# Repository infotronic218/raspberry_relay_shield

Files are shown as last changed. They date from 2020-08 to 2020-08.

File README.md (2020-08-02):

# Raspberry Pi 3 4 relays channels shield designed with Kicad

## The project is design using Kicad 5.1.5 

## The relay is drived by transistors

## Schematic

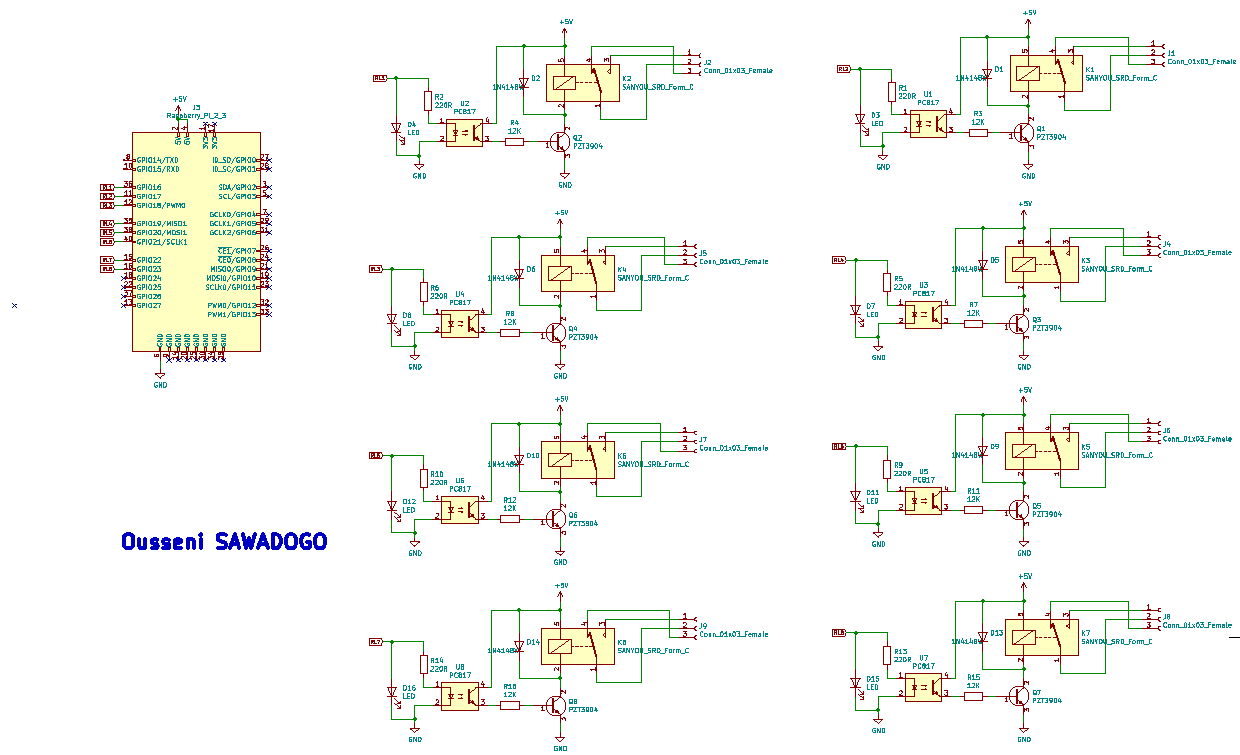
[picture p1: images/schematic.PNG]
Schematic


## Components side 
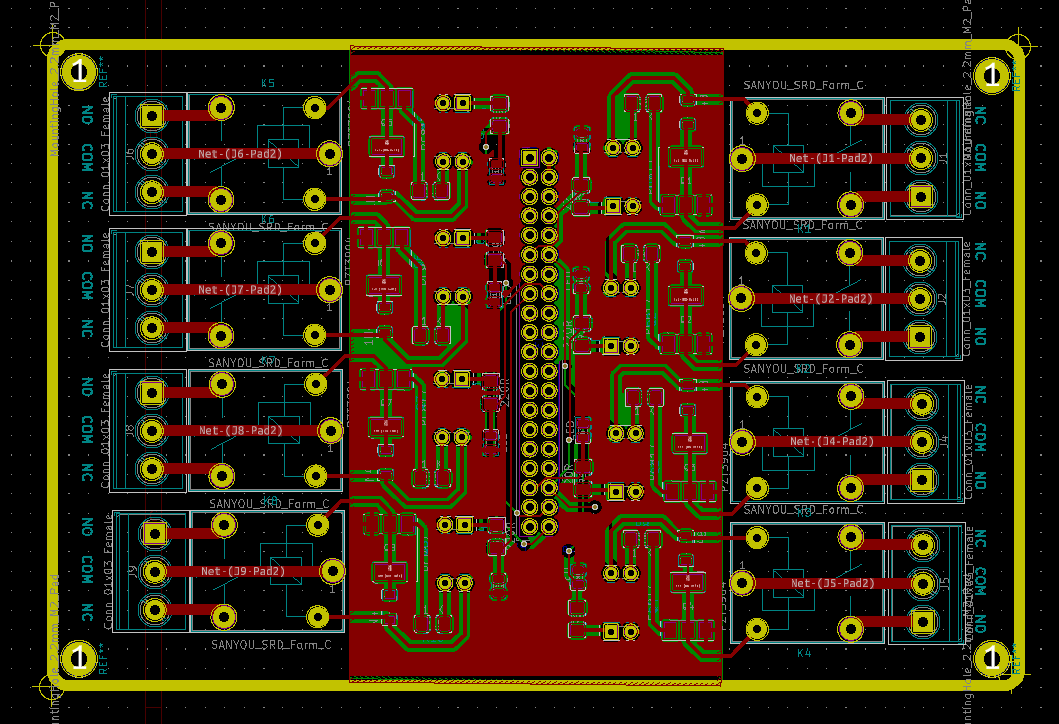
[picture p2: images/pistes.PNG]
Components side


## 3D View of the circuit
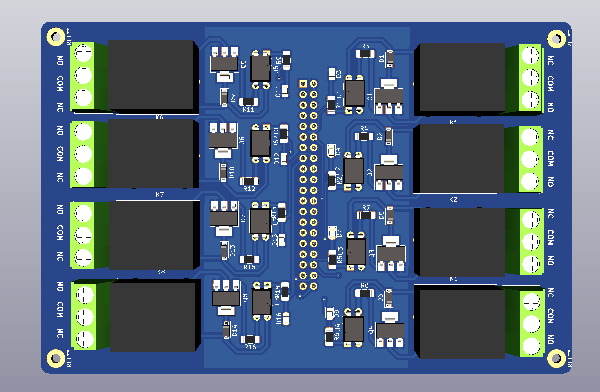
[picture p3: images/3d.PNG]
3D View


## To contact me 
[My portfolio at this url ](https://www.oussenisawadogo.me)

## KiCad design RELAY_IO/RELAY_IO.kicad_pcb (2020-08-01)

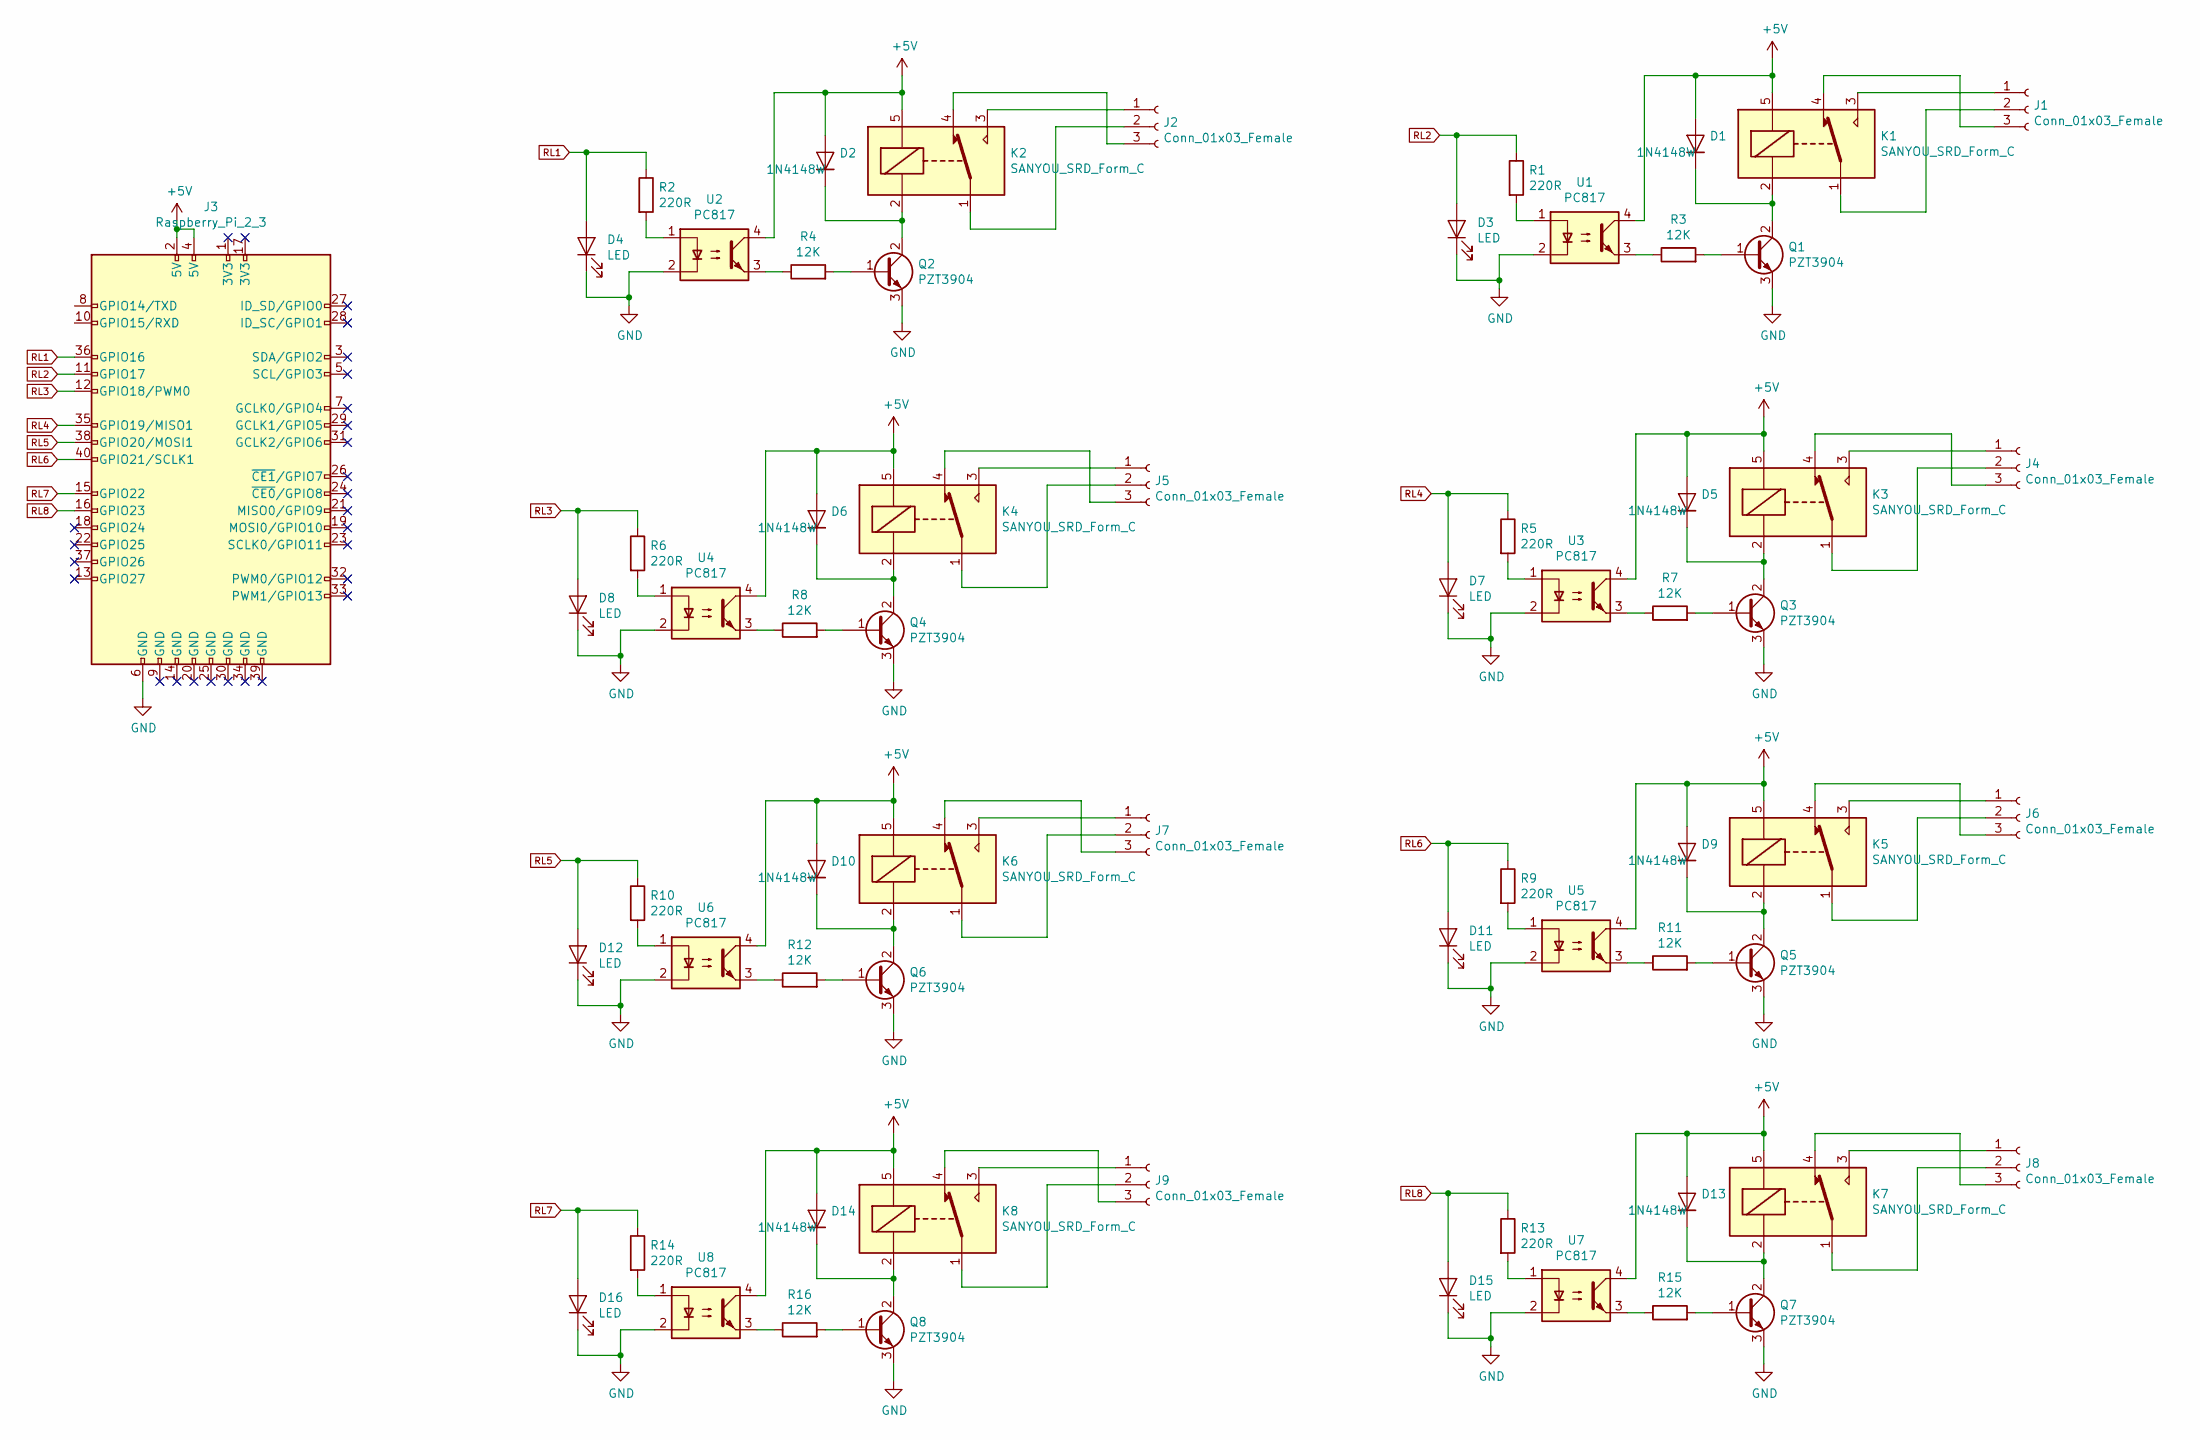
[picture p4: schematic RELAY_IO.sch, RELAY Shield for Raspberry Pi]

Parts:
D1, D2, D5, D6, D9, D10, D13, D14: 1N4148W; D_SOD-123
D3, D4, D7, D8, D11, D12, D15, D16: LED; LED_0805_2012Metric
J1, J2, J4, J5, J6, J7, J8, J9: Conn_01x03_Female; TerminalBlock_Phoenix_PT-1,5-3-5.0-H_1x03_P5.00mm_Horizontal
J3: Raspberry_Pi_2_3; PinSocket_2x20_P2.54mm_Vertical
K1, K2, K3, K4, K5, K6, K7, K8: SANYOU_SRD_Form_C; Relay_SPDT_SANYOU_SRD_Series_Form_C
Q1, Q2, Q3, Q4, Q5, Q6, Q7, Q8: PZT3904; SOT-223
R1, R2, R5, R6, R9, R10, R13, R14: 220R; R_1206_3216Metric_Pad1.42x1.75mm_HandSolder
R3, R4, R7, R8, R11, R12, R15, R16: 12K; R_1206_3216Metric_Pad1.42x1.75mm_HandSolder
U1, U2, U3, U4, U5, U6, U7, U8: PC817; DIP-4_W7.62mm

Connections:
+5V: D1.2 (A), D2.2 (A), D5.2 (A), D6.2 (A), D9.2 (A), D10.2 (A), D13.2 (A), D14.2 (A), J3.2 (5V), J3.4 (5V), K1.5, K2.5, K3.5, K4.5, K5.5, K6.5, K7.5, K8.5, U1.4, U2.4, U3.4, U4.4, U5.4, U6.4, U7.4, U8.4
GND: D3.1 (K), D4.1 (K), D7.1 (K), D8.1 (K), D11.1 (K), D12.1 (K), D15.1 (K), D16.1 (K), J3.6 (GND), Q1.3 (E), Q2.3 (E), Q3.3 (E), Q4.3 (E), Q5.3 (E), Q6.3 (E), Q7.3 (E), Q8.3 (E), U1.2, U2.2, U3.2, U4.2, U5.2, U6.2, U7.2, U8.2
unnamed: D1.1 (K), K1.2, Q1.2 (C), Q1.4 (C)
unnamed: D2.1 (K), K2.2, Q2.2 (C), Q2.4 (C)
unnamed: D5.1 (K), K3.2, Q3.2 (C), Q3.4 (C)
unnamed: D6.1 (K), K4.2, Q4.2 (C), Q4.4 (C)
unnamed: D9.1 (K), K5.2, Q5.2 (C), Q5.4 (C)
unnamed: D10.1 (K), K6.2, Q6.2 (C), Q6.4 (C)
unnamed: D13.1 (K), K7.2, Q7.2 (C), Q7.4 (C)
unnamed: D14.1 (K), K8.2, Q8.2 (C), Q8.4 (C)
unnamed: J1.1, K1.3
unnamed: J1.2, K1.1
unnamed: J1.3, K1.4
unnamed: J2.1, K2.3
unnamed: J2.2, K2.1
unnamed: J2.3, K2.4
unnamed: J4.1, K3.3
unnamed: J4.2, K3.1
unnamed: J4.3, K3.4
unnamed: J5.1, K4.3
unnamed: J5.2, K4.1
unnamed: J5.3, K4.4
unnamed: J6.1, K5.3
unnamed: J6.2, K5.1
unnamed: J6.3, K5.4
unnamed: J7.1, K6.3
unnamed: J7.2, K6.1
unnamed: J7.3, K6.4
unnamed: J8.1, K7.3
unnamed: J8.2, K7.1
unnamed: J8.3, K7.4
unnamed: J9.1, K8.3
unnamed: J9.2, K8.1
unnamed: J9.3, K8.4
unnamed: Q1.1 (B), R3.2
unnamed: Q2.1 (B), R4.2
unnamed: Q3.1 (B), R7.2
unnamed: Q4.1 (B), R8.2
unnamed: Q5.1 (B), R11.2
unnamed: Q6.1 (B), R12.2
unnamed: Q7.1 (B), R15.2
unnamed: Q8.1 (B), R16.2
unnamed: R1.2, U1.1
unnamed: R2.2, U2.1
unnamed: R3.1, U1.3
unnamed: R4.1, U2.3
unnamed: R5.2, U3.1
unnamed: R6.2, U4.1
unnamed: R7.1, U3.3
unnamed: R8.1, U4.3
unnamed: R9.2, U5.1
unnamed: R10.2, U6.1
unnamed: R11.1, U5.3
unnamed: R12.1, U6.3
unnamed: R13.2, U7.1
unnamed: R14.2, U8.1
unnamed: R15.1, U7.3
unnamed: R16.1, U8.3
RL1: D4.2 (A), J3.36 (GPIO16), R2.1
RL2: D3.2 (A), J3.11 (GPIO17), R1.1
RL3: D8.2 (A), J3.12 (GPIO18/PWM0), R6.1
RL4: D7.2 (A), J3.35 (GPIO19/MISO1), R5.1
RL5: D12.2 (A), J3.38 (GPIO20/MOSI1), R10.1
RL6: D11.2 (A), J3.40 (GPIO21/SCLK1), R9.1
RL7: D16.2 (A), J3.15 (GPIO22), R14.1
RL8: D15.2 (A), J3.16 (GPIO23), R13.1

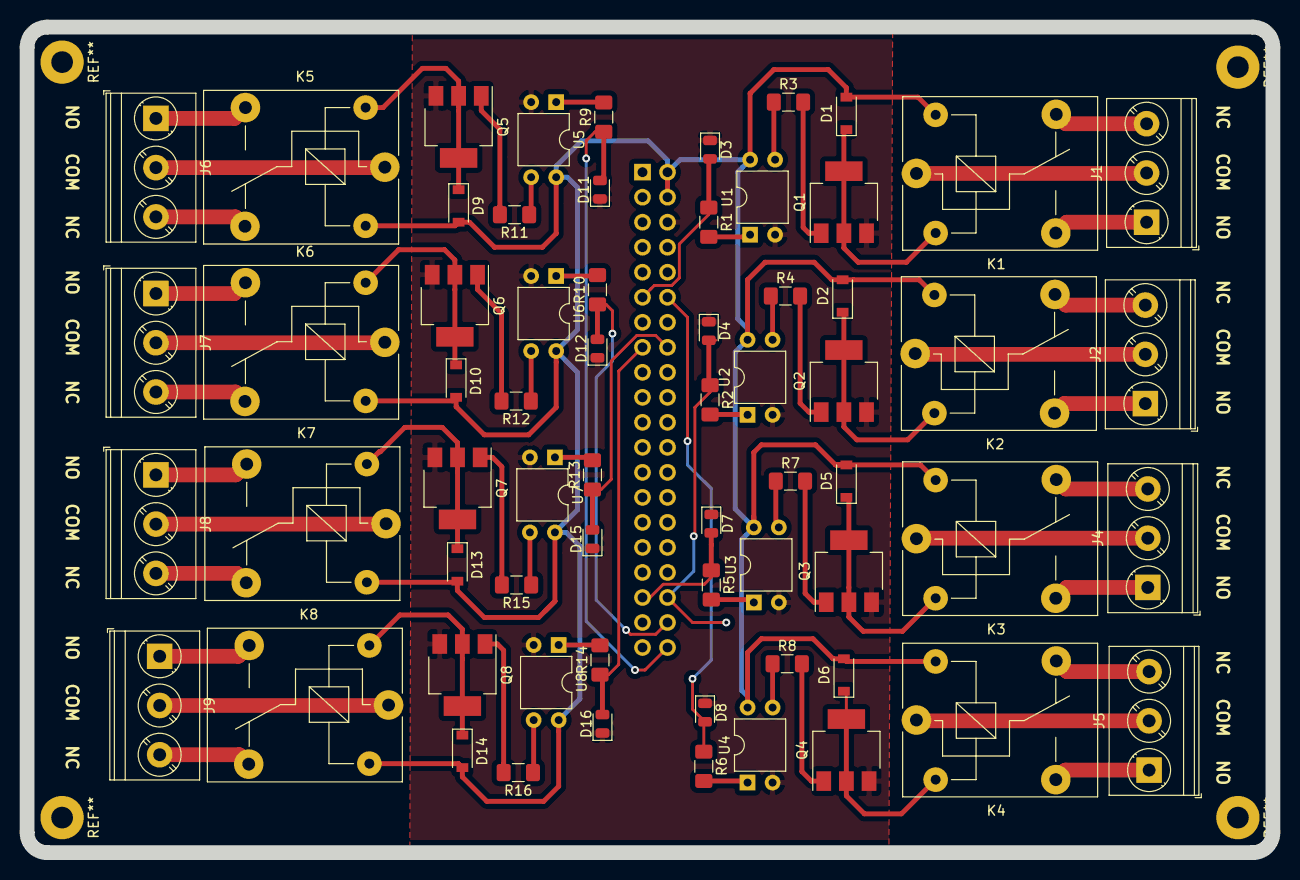
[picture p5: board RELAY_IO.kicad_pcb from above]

Board: 2 copper layers, 126.5 x 83.8 mm, 65 parts (1 on the bottom side), 66 nets.

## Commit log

2020-08-01 Push project to github
    [RELAY_IO.kicad_pcb, RELAY_IO.sch]
2020-08-02 Update of ny page
    [RELAY_IO.sch]
